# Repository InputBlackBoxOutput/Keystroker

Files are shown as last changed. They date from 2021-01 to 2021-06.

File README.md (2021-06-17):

# Keystroker
A USB HID device to perform USB drop attack

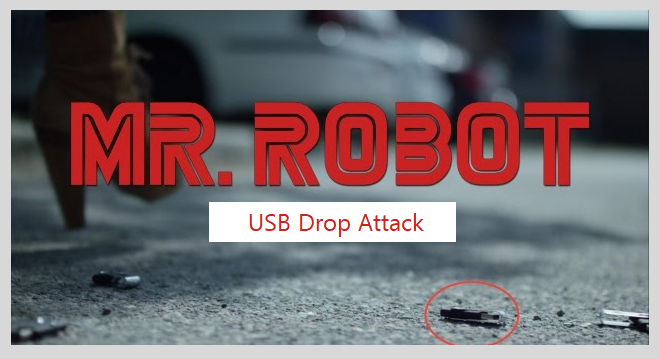
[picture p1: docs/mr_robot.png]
MR. ROBOT


Research presented at BlackHat USA 2016 by Elie Bursztein of Google’s anti-abuse research team shows that the danger is alarmingly real!

[Watch this video to know more](https://www.youtube.com/watch?v=ZI5fvU5QKwQ&feature=emb_logo)

## How it works?
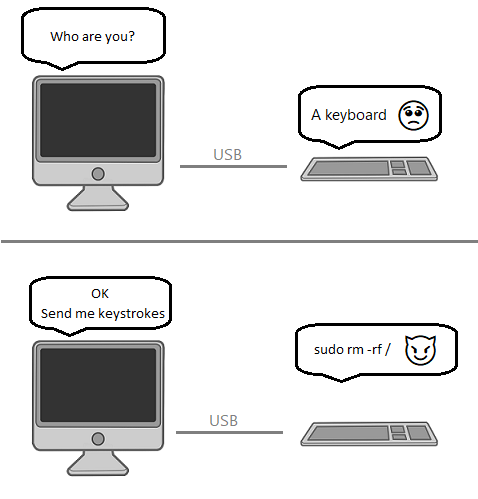
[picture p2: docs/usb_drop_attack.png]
USB Drop Attack


[Know more by reading these instructables](https://www.instructables.com/Keystroker-USB-Drop-Attack/)

## Steps to build the Keystroker 
1. Procure electronics components from a reliable source
1. Send the Gerber files to a PCB manufacturer to get a PCB made
1. 3D print the enclosure
1. Solder the components on the PCB, upload the firmware and test
1. Finally, mount the PCB in the enclosure

### Keystroker 3D render
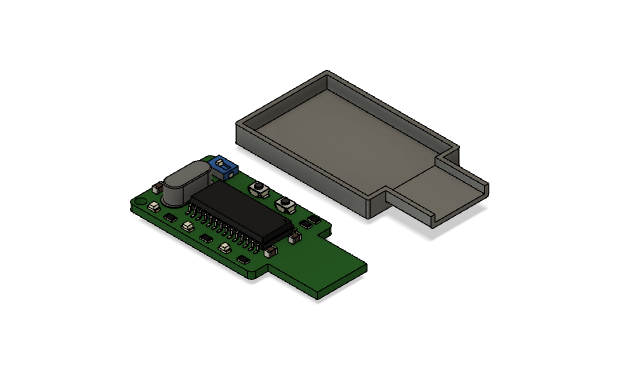
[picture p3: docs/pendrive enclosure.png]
render


### Demo 
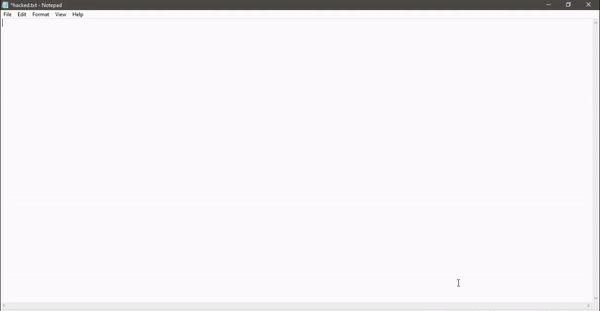
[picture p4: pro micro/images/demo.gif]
Demo


## If you prefer using an Arduino Pro Micro
1. Remove the USB receptacle  
1. Use superglue to attach a USB type A plug
1. Connect the pins of the USB type A plug to the USB receptacle pads
1. Upload the firmware 

##  Useful modification ideas
- A hardware utility to securely store passwords and enter them when required
- A fully customized keyboard for a very specific purpose. For instance, a keyboard with video editor shortcuts as keys

### Made with lots of ⏱️, 📚 and ☕ by InputBlackBoxOutput

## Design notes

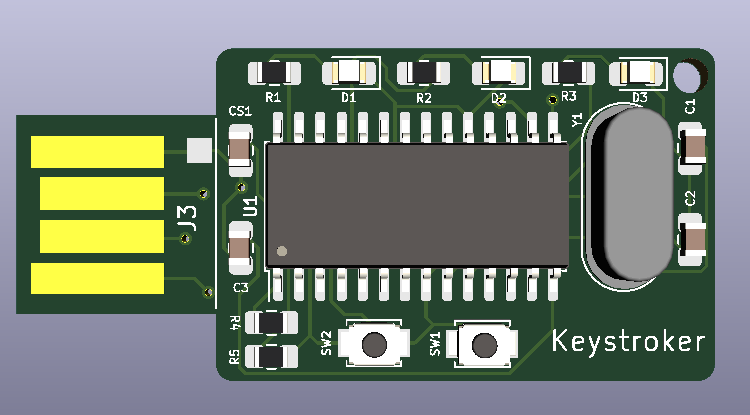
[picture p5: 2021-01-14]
docs/pendrive pcb top.png

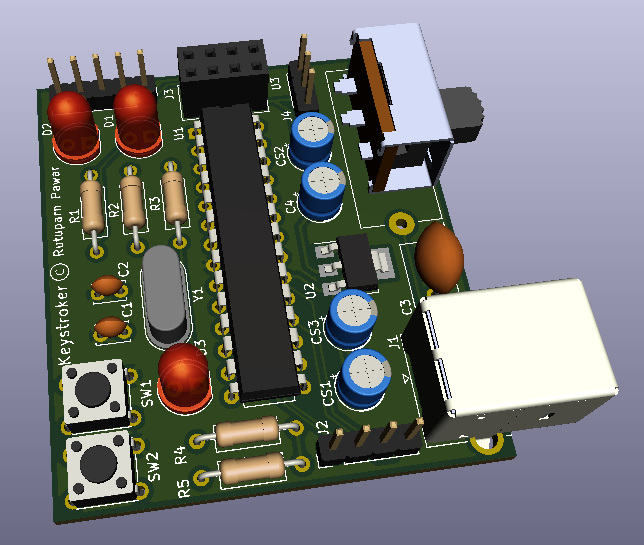
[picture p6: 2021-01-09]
docs/PCB 3D render.png

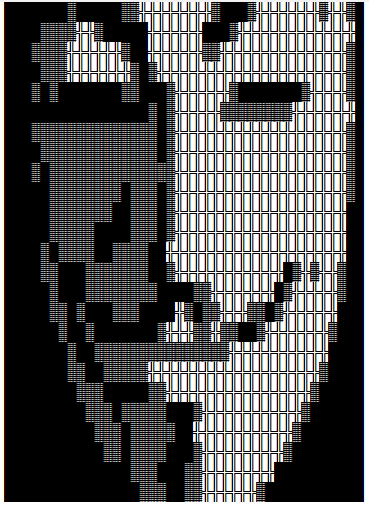
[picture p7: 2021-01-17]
docs/mask.png

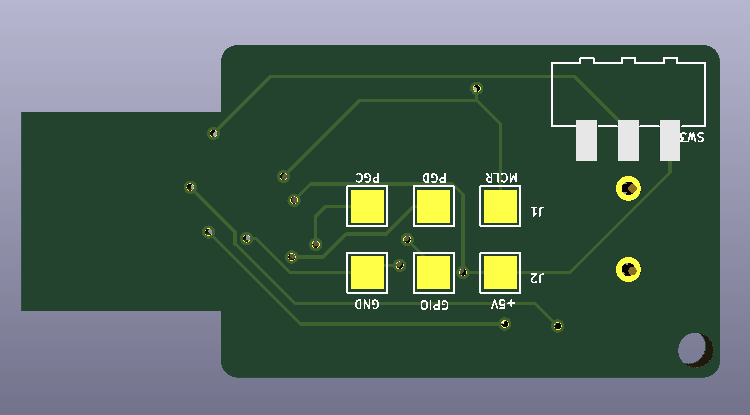
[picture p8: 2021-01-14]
docs/pendrive pcb bottom.png

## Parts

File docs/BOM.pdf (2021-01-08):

Id | Designator | Package | Quantity Designation
1 F1 | SPST_Switch_large | 1 | SW_SPST
2 J4 | PinHeader_1x03_P2.54mm_Vertical | 1 | Power
3 U3 | PinHeader_2x04_P2.54mm_Vertical | 1 | NRF24L01_Breakout
4 C3 | C_Disc_D8.0mm_W5.0mm_P5.00mm | 1 | 220nF
5 C4,CS2 | CP_Radial_D5.0mm_P2.50mm | 2 | 22uF
6 U2 | SOT-223-3_TabPin2 | 1 | AMS1117-3.3
7 J3 | PinHeader_1x05_P2.54mm_Vertical | 1 | Conn_01x05_Male
8 J2 | PinHeader_1x04_P2.54mm_Vertical | 1 | SPI
9 SW2,SW1 | SW_TH_Tactile_Omron_B3F-10xx | 2 | SW_Push
10 J1 | USB_B_OST_USB-B1HSxx_Horizontal | 1 | USB TYPE-B FEMALE
11 Y1 | Crystal_HC49-U_Vertical | 1 | 8Mhz
12 U1 | DIP-28_W7.62mm | 1 | PIC18F2550-ISP
13 R5,R4 | R_Axial_DIN0207_L6.3mm_D2.5mm_P10.16mm_Horizontal | 2 | 10k
14 R3,R2,R1 | R_Axial_DIN0207_L6.3mm_D2.5mm_P10.16mm_Horizontal | 3 | 1k
15 D3 | LED_D5.0mm | 1 | GREEN LED
16 D2 | LED_D5.0mm | 1 | YELLOW LED
17 D1 | LED_D5.0mm | 1 | RED LED
18 CS3,CS1 | CP_Radial_D5.0mm_P2.50mm | 2 | 10uF
19 C2,C1 | C_Disc_D3.4mm_W2.1mm_P2.50mm | 2 | 22pF

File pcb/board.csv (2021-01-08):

Id | Designator | Package | Quantity | Designation | Supplier and ref
1 |  | BlackBox_Back_Silkscreen | 1 | BlackBox
2 |  | Copyright_Front_Screen | 1 | Copyright_Front_Screen
3 | F1 | SPST_Switch_large | 1 | SW_SPST
4 | J4 | PinHeader_1x03_P2.54mm_Vertical | 1 | Power
5 | U3 | nRF24L01_Breakout | 1 | NRF24L01_Breakout
6 | C3 | C_Disc_D8.0mm_W5.0mm_P5.00mm | 1 | 220nF
7 | C4,CS2 | CP_Radial_D5.0mm_P2.50mm | 2 | 22uF
8 | U2 | SOT-223-3_TabPin2 | 1 | AMS1117-3.3
9 | J3 | PinHeader_1x05_P2.54mm_Vertical | 1 | Conn_01x05_Male
10 | J2 | PinHeader_1x04_P2.54mm_Vertical | 1 | SPI
11 | SW2,SW1 | SW_TH_Tactile_Omron_B3F-10xx | 2 | SW_Push
12 | J1 | USB_B_OST_USB-B1HSxx_Horizontal | 1 | USB TYPE-B FEMALE
13 | Y1 | Crystal_HC49-U_Vertical | 1 | 8Mhz
14 | U1 | DIP-28_W7.62mm | 1 | PIC18F2550-ISP
15 | R5,R4 | R_Axial_DIN0207_L6.3mm_D2.5mm_P10.16mm_Horizontal | 2 | 10k
16 | R3,R2,R1 | R_Axial_DIN0207_L6.3mm_D2.5mm_P10.16mm_Horizontal | 3 | 1k
17 | D3 | LED_D5.0mm | 1 | GREEN LED
18 | D2 | LED_D5.0mm | 1 | YELLOW LED
19 | D1 | LED_D5.0mm | 1 | RED LED
20 | CS3,CS1 | CP_Radial_D5.0mm_P2.50mm | 2 | 10uF
21 | C2,C1 | C_Disc_D3.4mm_W2.1mm_P2.50mm | 2 | 22pF

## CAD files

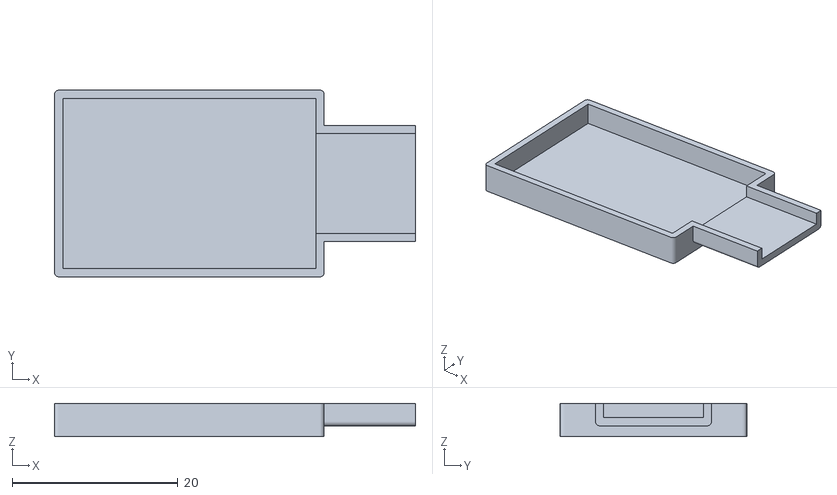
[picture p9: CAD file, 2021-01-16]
pendrive enclosure/model_stl.stl
43.5 x 22.5 x 4.00

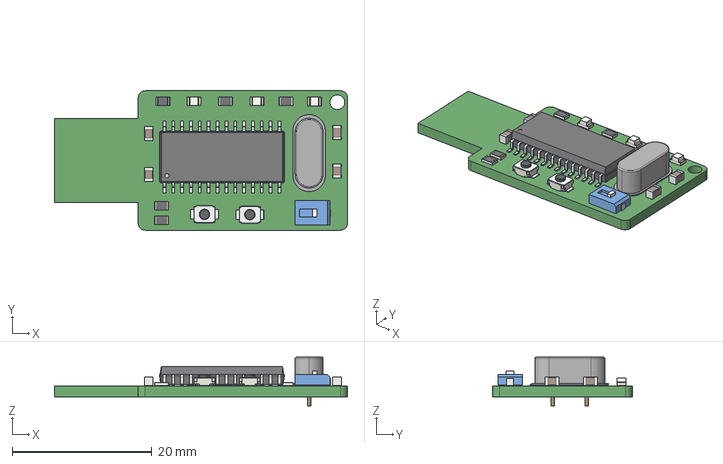
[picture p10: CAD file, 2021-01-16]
pendrive enclosure/board.step
42.0 x 20.0 x 7.00 mm

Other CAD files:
pendrive enclosure/model_obj.obj
pendrive enclosure/model.f3z

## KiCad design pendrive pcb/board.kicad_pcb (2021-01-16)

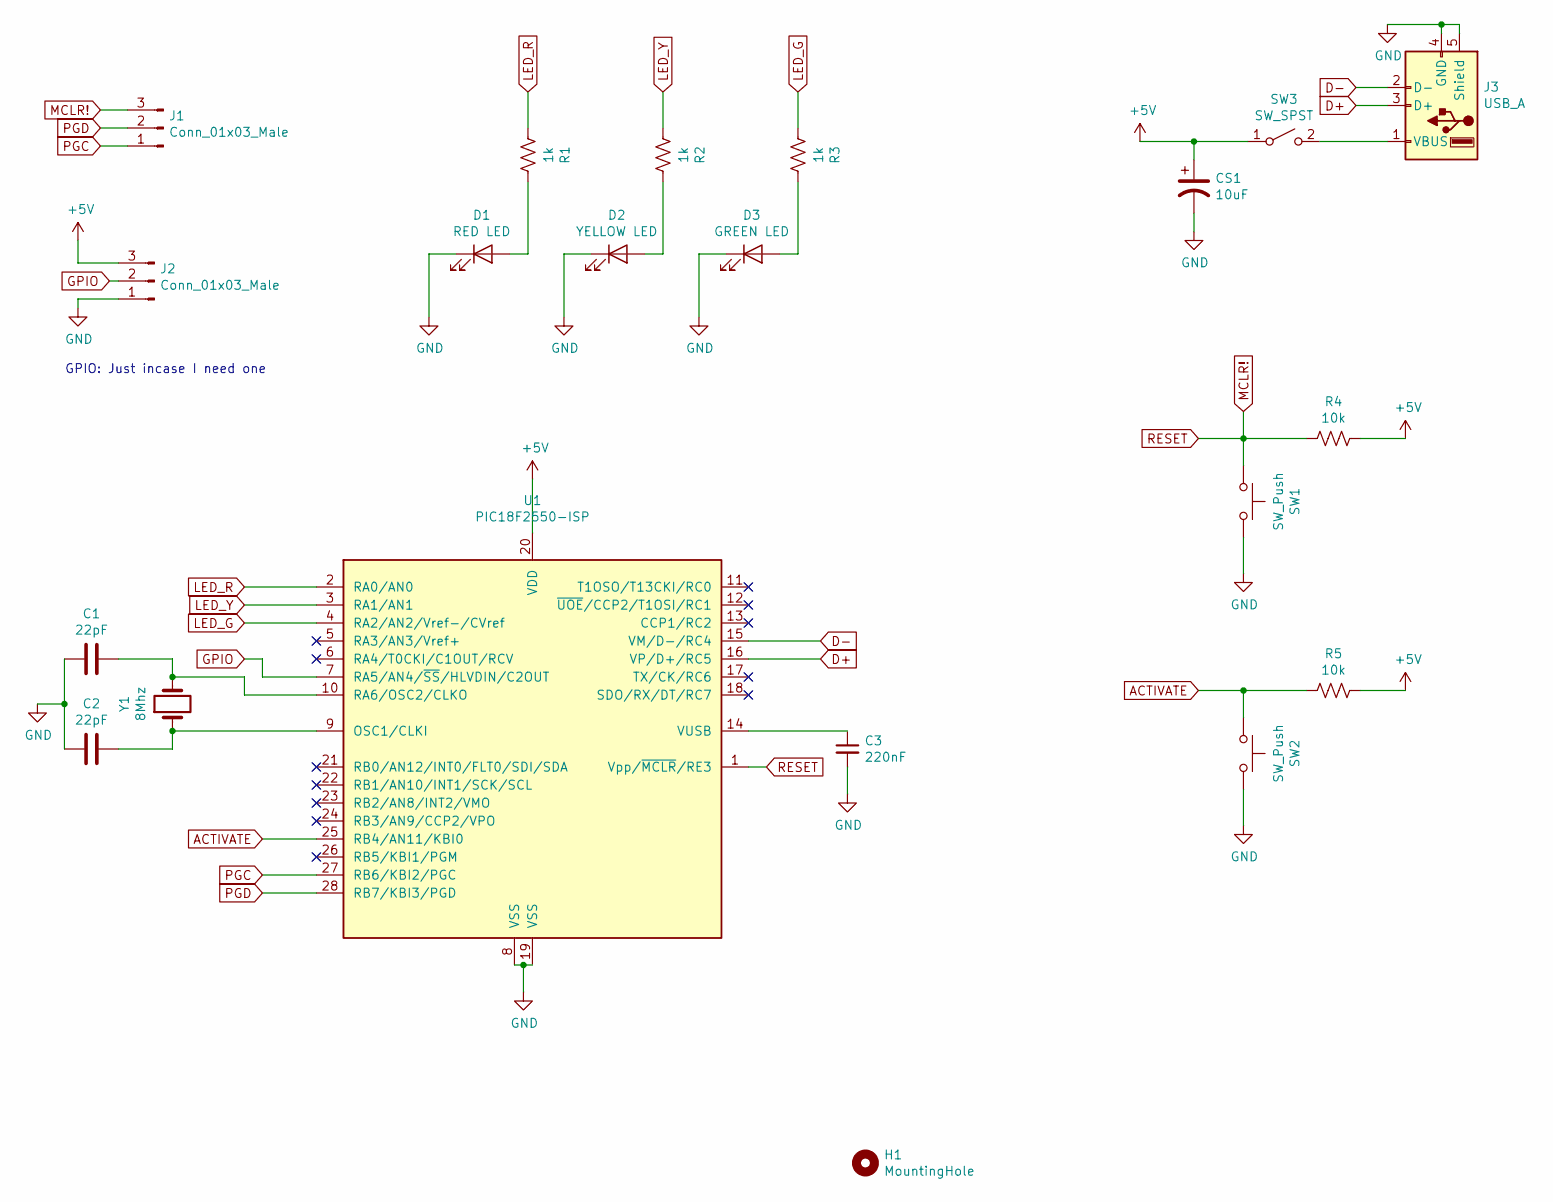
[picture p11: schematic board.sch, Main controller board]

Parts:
C1, C2: 22pF; C_0805_2012Metric_Pad1.15x1.40mm_HandSolder
C3: 220nF; C_0805_2012Metric_Pad1.15x1.40mm_HandSolder
CS1: 10uF; C_0805_2012Metric_Pad1.15x1.40mm_HandSolder
D1: RED LED; LED_0805_2012Metric_Pad1.15x1.40mm_HandSolder
D2: YELLOW LED; LED_0805_2012Metric_Pad1.15x1.40mm_HandSolder
D3: GREEN LED; LED_0805_2012Metric_Pad1.15x1.40mm_HandSolder
H1: MountingHole; MountingHole_2.1mm
J1, J2: Conn_01x03_Male; 3_pads
J3: USB_A; usb_pcb
R1, R2, R3: 1k; R_0805_2012Metric_Pad1.15x1.40mm_HandSolder
R4, R5: 10k; R_0805_2012Metric_Pad1.15x1.40mm_HandSolder
SW1, SW2: SW_Push; SW_SPST_B3U-1000P
SW3: SW_SPST; SW_SPST_EVQPE1
U1: PIC18F2550-ISP; SOIC-28W_7.5x17.9mm_P1.27mm
Y1: 8Mhz; Crystal_HC49-U_Vertical

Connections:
+5V: CS1.1, J2.3, R4.2, R5.2, SW3.1 (A), U1.20 (VDD)
ACTIVATE: R5.1, SW2.1, U1.25 (RB4/AN11/KBI0)
D+: J3.3 (D+), U1.16 (VP/D+/RC5)
D-: J3.2 (D-), U1.15 (VM/D-/RC4)
GND: C1.2, C2.2, C3.2, CS1.2, D1.1 (K), D2.1 (K), D3.1 (K), J2.1, J3.4 (GND), J3.5 (Shield), SW1.2, SW2.2, U1.8 (VSS), U1.19 (VSS)
GPIO: J2.2, U1.7 (RA5/AN4/~SS~/HLVDIN/C2OUT)
LED_G: R3.1, U1.4 (RA2/AN2/Vref-/CVref)
LED_R: R1.1, U1.2 (RA0/AN0)
LED_Y: R2.1, U1.3 (RA1/AN1)
MCLR!: J1.3, R4.1, SW1.1, U1.1 (Vpp/~MCLR~/RE3)
unnamed: C1.1, U1.10 (RA6/OSC2/CLKO), Y1.2
unnamed: C2.1, U1.9 (OSC1/CLKI), Y1.1
unnamed: C3.1, U1.14 (VUSB)
unnamed: D1.2 (A), R1.2
unnamed: D2.2 (A), R2.2
unnamed: D3.2 (A), R3.2
unnamed: J3.1 (VBUS), SW3.2 (B)
PGC: J1.1, U1.27 (RB6/KBI2/PGC)
PGD: J1.2, U1.28 (RB7/KBI3/PGD)

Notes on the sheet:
GPIO: Just incase I need one

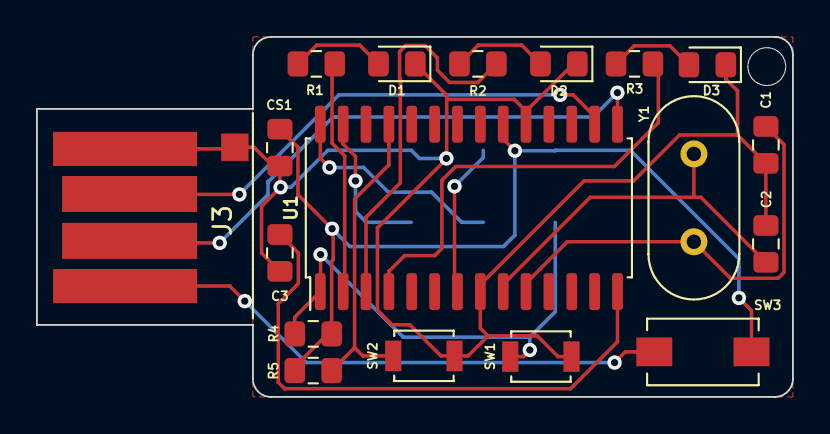
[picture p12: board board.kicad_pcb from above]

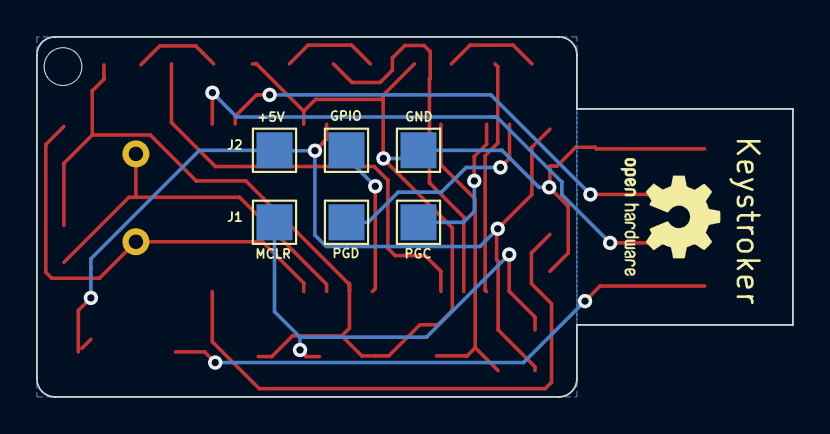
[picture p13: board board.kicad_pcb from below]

Board: 2 copper layers, 42.0 x 20.0 mm, 21 parts (2 on the bottom side), 19 nets.

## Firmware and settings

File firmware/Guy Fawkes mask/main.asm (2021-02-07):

_interrupt:

;main.c,10 :: 		void interrupt() {
;main.c,11 :: 		USB_Interrupt_Proc();
	CALL        _USB_Interrupt_Proc+0, 0
;main.c,12 :: 		}
L_end_interrupt:
L__interrupt2:
	RETFIE      1
; end of _interrupt

_main:

;main.c,15 :: 		void main() {
;main.c,16 :: 		keyboardInit();
	CALL        _keyboardInit+0, 0
;main.c,17 :: 		Delay_ms(2000);
	MOVLW       122
	MOVWF       R11, 0
	MOVLW       193
	MOVWF       R12, 0
	MOVLW       129
	MOVWF       R13, 0
L_main0:
	DECFSZ      R13, 1, 1
	BRA         L_main0
	DECFSZ      R12, 1, 1
	BRA         L_main0
	DECFSZ      R11, 1, 1
	BRA         L_main0
	NOP
	NOP
;main.c,19 :: 		sendText("        .:+oooooooooooooooooooo+:.        \r");
	MOVLW       ?lstr1_main+0
	MOVWF       FARG_sendText+0 
	MOVLW       hi_addr(?lstr1_main+0)
	MOVWF       FARG_sendText+1 
	CALL        _sendText+0, 0
;main.c,20 :: 		sendText("    -ooo+:.                    .:+ooo-    \r");
	MOVLW       ?lstr2_main+0
	MOVWF       FARG_sendText+0 
	MOVLW       hi_addr(?lstr2_main+0)
	MOVWF       FARG_sendText+1 
	CALL        _sendText+0, 0
;main.c,21 :: 		sendText("   ss.                              .ss   \r");
	MOVLW       ?lstr3_main+0
	MOVWF       FARG_sendText+0 
	MOVLW       hi_addr(?lstr3_main+0)
	MOVWF       FARG_sendText+1 
	CALL        _sendText+0, 0
;main.c,22 :: 		sendText("  .N      ..                  ..      N.  \r");
	MOVLW       ?lstr4_main+0
	MOVWF       FARG_sendText+0 
	MOVLW       hi_addr(?lstr4_main+0)
	MOVWF       FARG_sendText+1 
	CALL        _sendText+0, 0
;main.c,23 :: 		sendText("  :h /yyyyoo+oo:.        .:oo+ooyyyy/ h:  \r");
	MOVLW       ?lstr5_main+0
	MOVWF       FARG_sendText+0 
	MOVLW       hi_addr(?lstr5_main+0)
	MOVWF       FARG_sendText+1 
	CALL        _sendText+0, 0
;main.c,24 :: 		sendText("  ossd+:-:+oo:-:oo-    -oo:.:oo/:-:+dsso  \r");
	MOVLW       ?lstr6_main+0
	MOVWF       FARG_sendText+0 
	MOVLW       hi_addr(?lstr6_main+0)
	MOVWF       FARG_sendText+1 
	CALL        _sendText+0, 0
;main.c,25 :: 		sendText("  y+-        :oo/do    oy/oo:        -+y  \r");
	MOVLW       ?lstr7_main+0
	MOVWF       FARG_sendText+0 
	MOVLW       hi_addr(?lstr7_main+0)
	MOVWF       FARG_sendText+1 
	CALL        _sendText+0, 0
;main.c,26 :: 		sendText("  h+.    .......:os.    .:.......    .+h  \r");
	MOVLW       ?lstr8_main+0
	MOVWF       FARG_sendText+0 
	MOVLW       hi_addr(?lstr8_main+0)
	MOVWF       FARG_sendText+1 
	CALL        _sendText+0, 0
;main.c,27 :: 		sendText("  d+y/:/yo++/+oy: :d     :yo+/++oy/:/y+d  \r");
	MOVLW       ?lstr9_main+0
	MOVWF       FARG_sendText+0 
	MOVLW       hi_addr(?lstr9_main+0)
	MOVWF       FARG_sendText+1 
	CALL        _sendText+0, 0
;main.c,28 :: 		sendText("  m. ---/++++++/.  m.    ./++++++/--- .m  \r");
	MOVLW       ?lstr10_main+0
	MOVWF       FARG_sendText+0 
	MOVLW       hi_addr(?lstr10_main+0)
	MOVWF       FARG_sendText+1 
	CALL        _sendText+0, 0
;main.c,29 :: 		sendText("  m.               d:                 .m  \r");
	MOVLW       ?lstr11_main+0
	MOVWF       FARG_sendText+0 
	MOVLW       hi_addr(?lstr11_main+0)
	MOVWF       FARG_sendText+1 
	CALL        _sendText+0, 0
;main.c,30 :: 		sendText("  d-               y/                 -d  \r");
	MOVLW       ?lstr12_main+0
	MOVWF       FARG_sendText+0 
	MOVLW       hi_addr(?lstr12_main+0)
	MOVWF       FARG_sendText+1 
	CALL        _sendText+0, 0
;main.c,31 :: 		sendText("  os/         -    s+      -         /so  \r");
	MOVLW       ?lstr13_main+0
	MOVWF       FARG_sendText+0 
	MOVLW       hi_addr(?lstr13_main+0)
	MOVWF       FARG_sendText+1 
	CALL        _sendText+0, 0
;main.c,32 :: 		sendText("  .mso/::://oom .- :-   -. moo//:::/osm.  \r");
	MOVLW       ?lstr14_main+0
	MOVWF       FARG_sendText+0 
	MOVLW       hi_addr(?lstr14_main+0)
	MOVWF       FARG_sendText+1 
	CALL        _sendText+0, 0
;main.c,33 :: 		sendText("   +y :dyd/.  /oymy/--/ymho/  ./dyd: y+   \r");
	MOVLW       ?lstr15_main+0
	MOVWF       FARG_sendText+0 
	MOVLW       hi_addr(?lstr15_main+0)
	MOVWF       FARG_sendText+1 
	CALL        _sendText+0, 0
;main.c,34 :: 		sendText("    y+  yyy+//::ss.:yy:.ss:://+yyy  +y    \r");
	MOVLW       ?lstr16_main+0
	MOVWF       FARG_sendText+0 
	MOVLW       hi_addr(?lstr16_main+0)
	MOVWF       FARG_sendText+1 
	CALL        _sendText+0, 0
;main.c,35 :: 		sendText("     h/  +sso+++/-:y++y:-/++ooss+  /h     \r");
	MOVLW       ?lstr17_main+0
	MOVWF       FARG_sendText+0 
	MOVLW       hi_addr(?lstr17_main+0)
	MOVWF       FARG_sendText+1 
	CALL        _sendText+0, 0
;main.c,36 :: 		sendText("     .h:   ..--:shho//ohhy:--..   /h.     \r");
	MOVLW       ?lstr18_main+0
	MOVWF       FARG_sendText+0 
	MOVLW       hi_addr(?lstr18_main+0)
	MOVWF       FARG_sendText+1 
	CALL        _sendText+0, 0
;main.c,37 :: 		sendText("       y+       .sysssshs.       +y       \r");
	MOVLW       ?lstr19_main+0
	MOVWF       FARG_sendText+0 
	MOVLW       hi_addr(?lstr19_main+0)
	MOVWF       FARG_sendText+1 
	CALL        _sendText+0, 0
;main.c,38 :: 		sendText("        +y.      .ss  ss.      .y+        \r");
	MOVLW       ?lstr20_main+0
	MOVWF       FARG_sendText+0 
	MOVLW       hi_addr(?lstr20_main+0)
	MOVWF       FARG_sendText+1 
	CALL        _sendText+0, 0
;main.c,39 :: 		sendText("         -yo      y/  /y      oy-         \r");
	MOVLW       ?lstr21_main+0
	MOVWF       FARG_sendText+0 
	MOVLW       hi_addr(?lstr21_main+0)
	MOVWF       FARG_sendText+1 
	CALL        _sendText+0, 0
;main.c,40 :: 		sendText("           :y+    h:  :h    +y:           \r");
	MOVLW       ?lstr22_main+0
	MOVWF       FARG_sendText+0 
	MOVLW       hi_addr(?lstr22_main+0)
	MOVWF       FARG_sendText+1 
	CALL        _sendText+0, 0
;main.c,41 :: 		sendText("             :so- +s  s+ -ss:             \r");
	MOVLW       ?lstr23_main+0
	MOVWF       FARG_sendText+0 
	MOVLW       hi_addr(?lstr23_main+0)
	MOVWF       FARG_sendText+1 
	CALL        _sendText+0, 0
;main.c,42 :: 		sendText("               .+osmoomso+.               \r");
	MOVLW       ?lstr24_main+0
	MOVWF       FARG_sendText+0 
	MOVLW       hi_addr(?lstr24_main+0)
	MOVWF       FARG_sendText+1 
	CALL        _sendText+0, 0
;main.c,45 :: 		sendText("\r");
	MOVLW       ?lstr25_main+0
	MOVWF       FARG_sendText+0 
	MOVLW       hi_addr(?lstr25_main+0)
	MOVWF       FARG_sendText+1 
	CALL        _sendText+0, 0
;main.c,46 :: 		sendText("\r");
	MOVLW       ?lstr26_main+0
	MOVWF       FARG_sendText+0 
	MOVLW       hi_addr(?lstr26_main+0)
	MOVWF       FARG_sendText+1 
	CALL        _sendText+0, 0
;main.c,47 :: 		sendText("You have been hacked! ;-)\r");
	MOVLW       ?lstr27_main+0
	MOVWF       FARG_sendText+0 
	MOVLW       hi_addr(?lstr27_main+0)
	MOVWF       FARG_sendText+1 
	CALL        _sendText+0, 0
;main.c,48 :: 		}
L_end_main:
	GOTO        $+0
; end of _main

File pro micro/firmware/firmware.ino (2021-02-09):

// Connect as keyboard and send key strokes for Guy Fawkes mask ASCII art
// Written by Rutuparn Pawar (InputBlackBoxOutput)
// Created 9 Feb 2020

// Caution: Connect a switch to cut the power in case of an emergency


#include <Keyboard.h>

void setup() {
  Keyboard.begin();
}

void loop() {
  delay(1000);
  
  Keyboard.print("          .:+oooooooooooooooooooo+:.          \n");
  Keyboard.print("      -ooo+:.                    .:+ooo-      \n");
  Keyboard.print("     ss.                              .ss     \n");
  Keyboard.print("    .N      ..                  ..      N.    \n");
  Keyboard.print("    :h /yyyyoo+oo:.        .:oo+ooyyyy/ h:    \n");
  Keyboard.print("    ossd+:-:+oo:-:oo-    -oo:.:oo/:-:+dsso    \n");
  Keyboard.print("    y+-        :oo/do    oy/oo:        -+y    \n");
  Keyboard.print("    h+.    .......:os.    .:.......    .+h    \n");
  Keyboard.print("    d+y/:/yo++/+oy: :d     :yo+/++oy/:/y+d    \n");
  Keyboard.print("    m. ---/++++++/.  m.    ./++++++/--- .m    \n");
  Keyboard.print("    m.               d:                 .m    \n");
  Keyboard.print("    d-               y/                 -d    \n");
  Keyboard.print("    os/         -    s+      -         /so    \n");
  Keyboard.print("    .mso/::://oom .- :-   -. moo//:::/osm.    \n");
  Keyboard.print("     +y :dyd/.  /oymy/--/ymho/  ./dyd: y+     \n");
  Keyboard.print("      y+  yyy+//::ss.:yy:.ss:://+yyy  +y      \n");
  Keyboard.print("       h/  +sso+++/-:y++y:-/++ooss+  /h       \n");
  Keyboard.print("       .h:   ..--:shho//ohhy:--..   /h.       \n");
  Keyboard.print("         y+       .sysssshs.       +y         \n");
  Keyboard.print("          +y.      .ss  ss.      .y+          \n");
  Keyboard.print("           -yo      y/  /y      oy-           \n");
  Keyboard.print("             :y+    h:  :h    +y:             \n");
  Keyboard.print("               :so- +s  s+ -ss:               \n");
  Keyboard.print("                 .+osmoomso+.                 \n\n\n");

  delay(1000);
  Keyboard.print("You ");
  delay(500);
  Keyboard.print("have ");
  delay(500);
  Keyboard.print("been ");
  delay(500);
  Keyboard.print("hacked!\n\n");

  delay(5000);
  Keyboard.print("Just kidding.\n\n");

  while(1);
}


/*
// Place cursor here while uploading or get ready to face the wrath of the keystroker ;-)



*/

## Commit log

2021-01-06 PCB added
    [board.csv, board.dsn, board.kicad_pcb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]
2021-01-06 Test codes added
    [blink.cfg, sequencer.cfg]
2021-01-08 BOM and PCB 3D render added
    [board.csv, board.kicad_pcb]
2021-01-09 Ground plane added to PCB
    [board.kicad_pcb]
2021-01-14 Pendrive PCB added
    [board.csv, board.dsn, board.kicad_pcb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]
2021-01-16 Switch moved to top
    [board.kicad_pcb, board.sch]
2021-01-16 3D model for enclosure added
    [board.step, model.f3z, model_obj.obj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]
2021-01-21 INGAME firmware added
    [INGAME.cfg]
2021-02-07 Guy Fawkes mask firmware added
    [mask.cfg]
2021-02-09 Arduino pro micro code added

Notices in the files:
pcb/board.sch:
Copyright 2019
